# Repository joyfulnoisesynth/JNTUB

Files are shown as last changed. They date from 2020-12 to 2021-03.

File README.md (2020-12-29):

# JoyfulNoise Tiny Utility Board

A versatile ATtiny85-powered Eurorack module in 4HP.

## License

JoyfulNoise hardware and software is Open Source.

The JNTUB hardware is licensed under Creative Commons: [CC-BY-SA-4.0: Attribution / ShareAlike](https://creativecommons.org/licenses/by-sa/4.0/).

The JNTUB firmware is licensed under the GNU General Public License: [GPLv3](https://www.gnu.org/licenses/gpl-3.0-standalone.html).

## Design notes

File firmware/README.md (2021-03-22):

# Joyful Noise Tiny Utility Board Firmware

## Firmware To-Do

### ENV
- [x] Initial implementation
- [x] Refactor to use `FastClock`
- [ ] Make retrig optional
- [ ] Use 10-bit PWM?

### LFO
- [x] Initial implementation
- [x] 10-bit PWM
- [x] Automatic clock detection
- [ ] Fix buggy clock tracking
- [ ] Allow control of amplitude

### VCO
- [x] Initial implementation
- [ ] Adjust SUB/DTN knob response to reflect panel graphics
- [ ] Investigate waveform glitches
- [ ] Ensure audio-rate sync works
- [ ] Experiment with 10-bit audio?
- [ ] Experiment with band-limited wavetables?

### RAND
- [x] Initial implementation
- [ ] Allow control of randomness and/or slew
- [ ] Make it faster?

### Beat Tool
- [x] Implement clock generation
- [x] Implement clock division
- [x] Implement clock multiplication
- [x] Implement burst generation
- [ ] Refactor to use `FastClock`
- [ ] Program the "internal clock" signal chain logic
- [ ] Implement swing
- [ ] Implement gate delay
- [ ] Implement gate lengthen
- [ ] Implement random sequencing
- [ ] Implement euclidean sequencing

### QUANT
- [ ] Initial implementation

### CV Tool
- [ ] Initial implementation

### µTM
- [ ] Initial implementation
- [ ] Implement random gates
- [ ] Implement chaining

### RAT
- [x] Port and test Muskrat firmware
- [ ] Improve user interface

### DSL
- [ ] Port and test Dialup firmware
- [ ] Improve user interface

### STRANG
- [x] Initial Karplus-Strong implementation
- [ ] Much more experimenting to get a decent instrument out of it
- [ ] Experiment with 10-bit audio?

### LFG
- [ ] Initial implementation

### CHRD
- [ ] Initial implementation

### GRNS
- [ ] Port and test Grains firmware
- [ ] Port and test alternative Grains firmwares?
- [ ] Port and test TOOL firmwares?

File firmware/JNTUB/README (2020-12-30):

JoyfulNoise Tiny Utility Board Firmware Library
-----------------------------------------------

This is the library that houses common code that can be used by any
JNTUB-based Eurorack module.

=== USAGE ===

To get this to work with Arduino IDE, you'll need to create a symlink/hardlink
to the firmware/JNTUB/ directory in your Arduino libraries directory.

See <https://www.arduino.cc/en/hacking/libraries> for details.

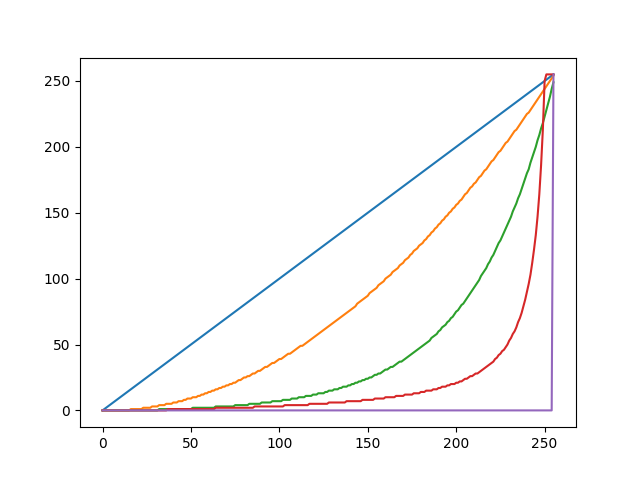
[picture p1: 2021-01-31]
firmware/ENV/curves.png

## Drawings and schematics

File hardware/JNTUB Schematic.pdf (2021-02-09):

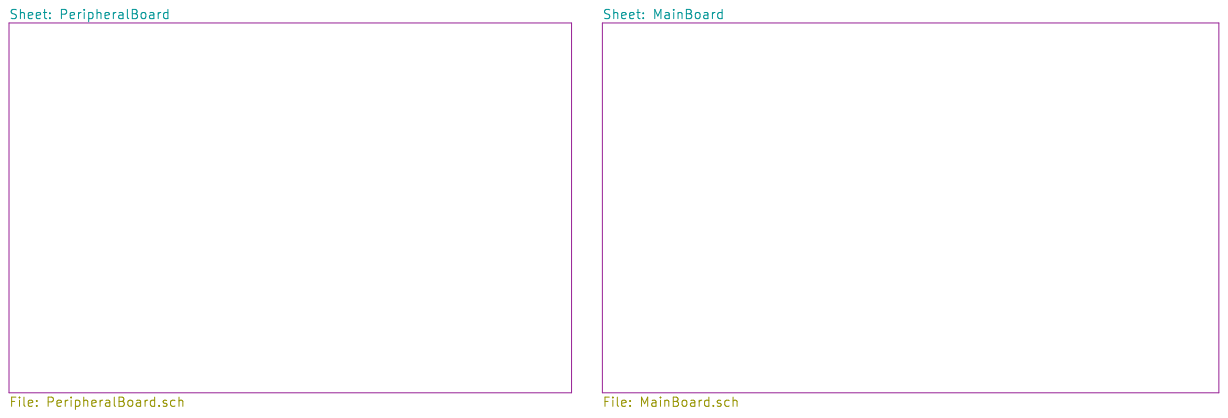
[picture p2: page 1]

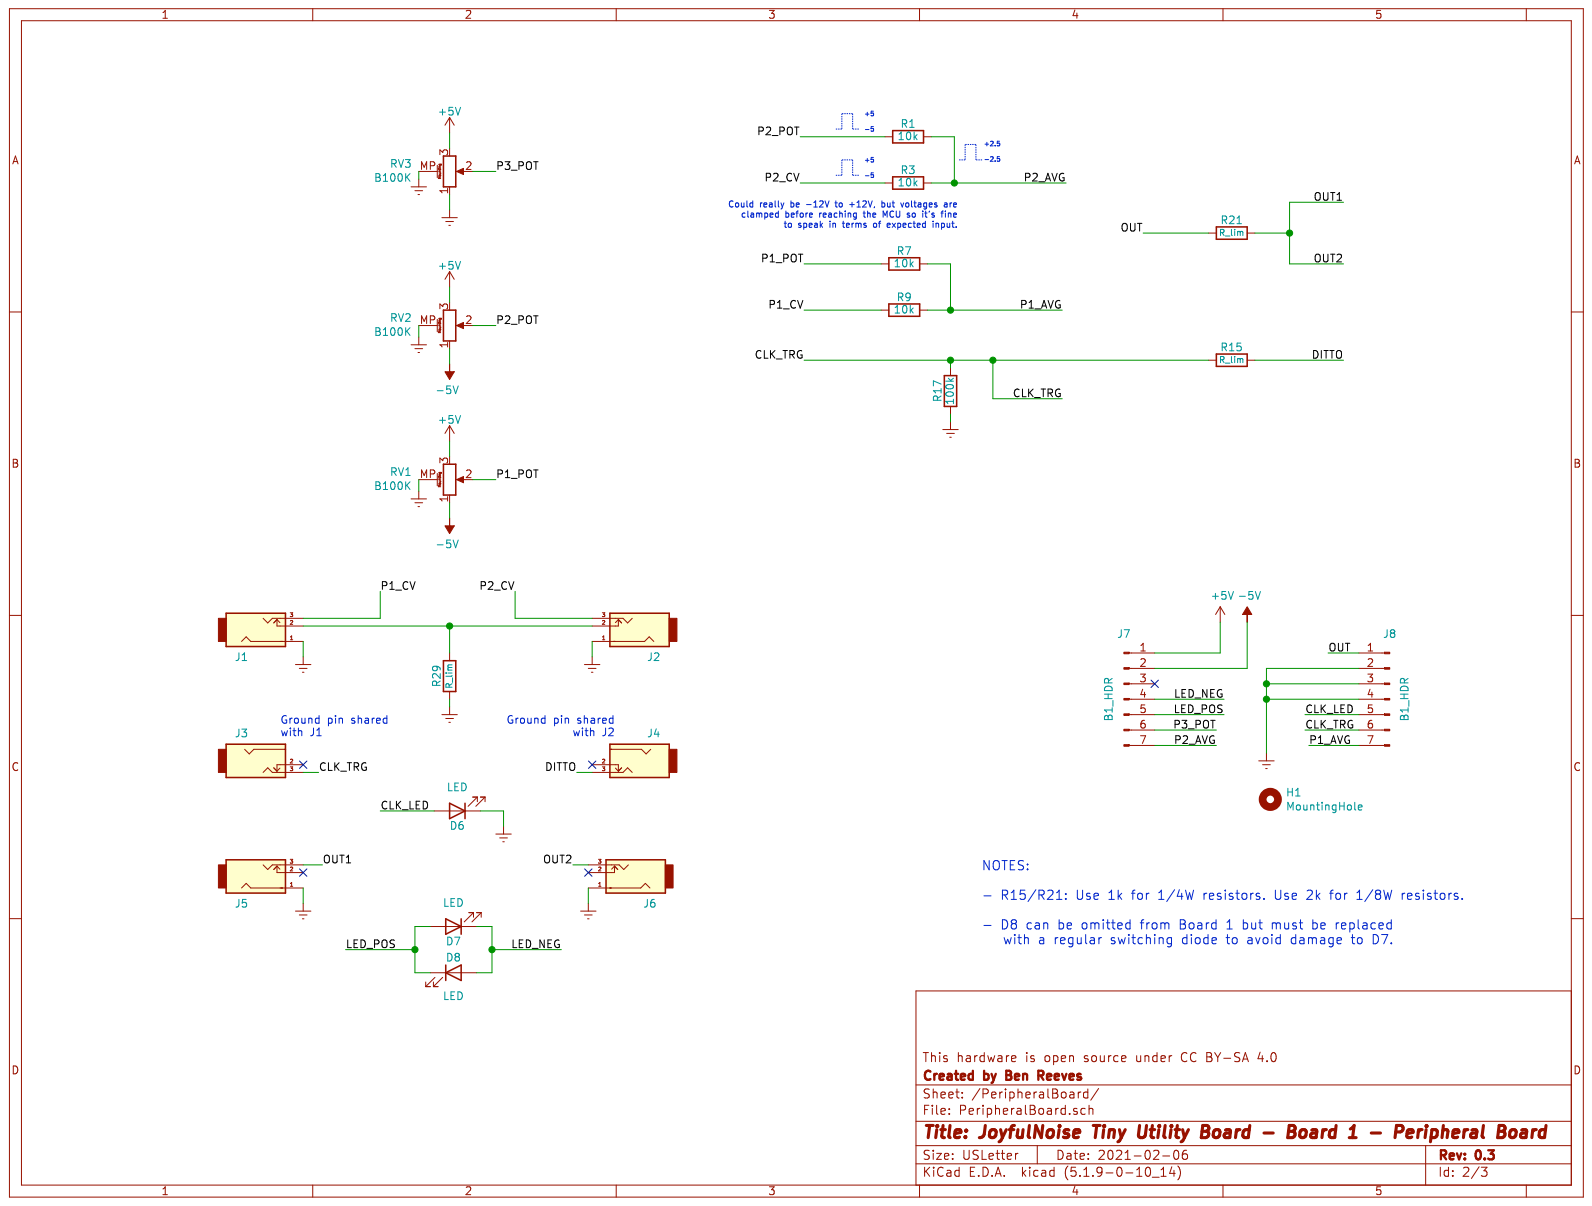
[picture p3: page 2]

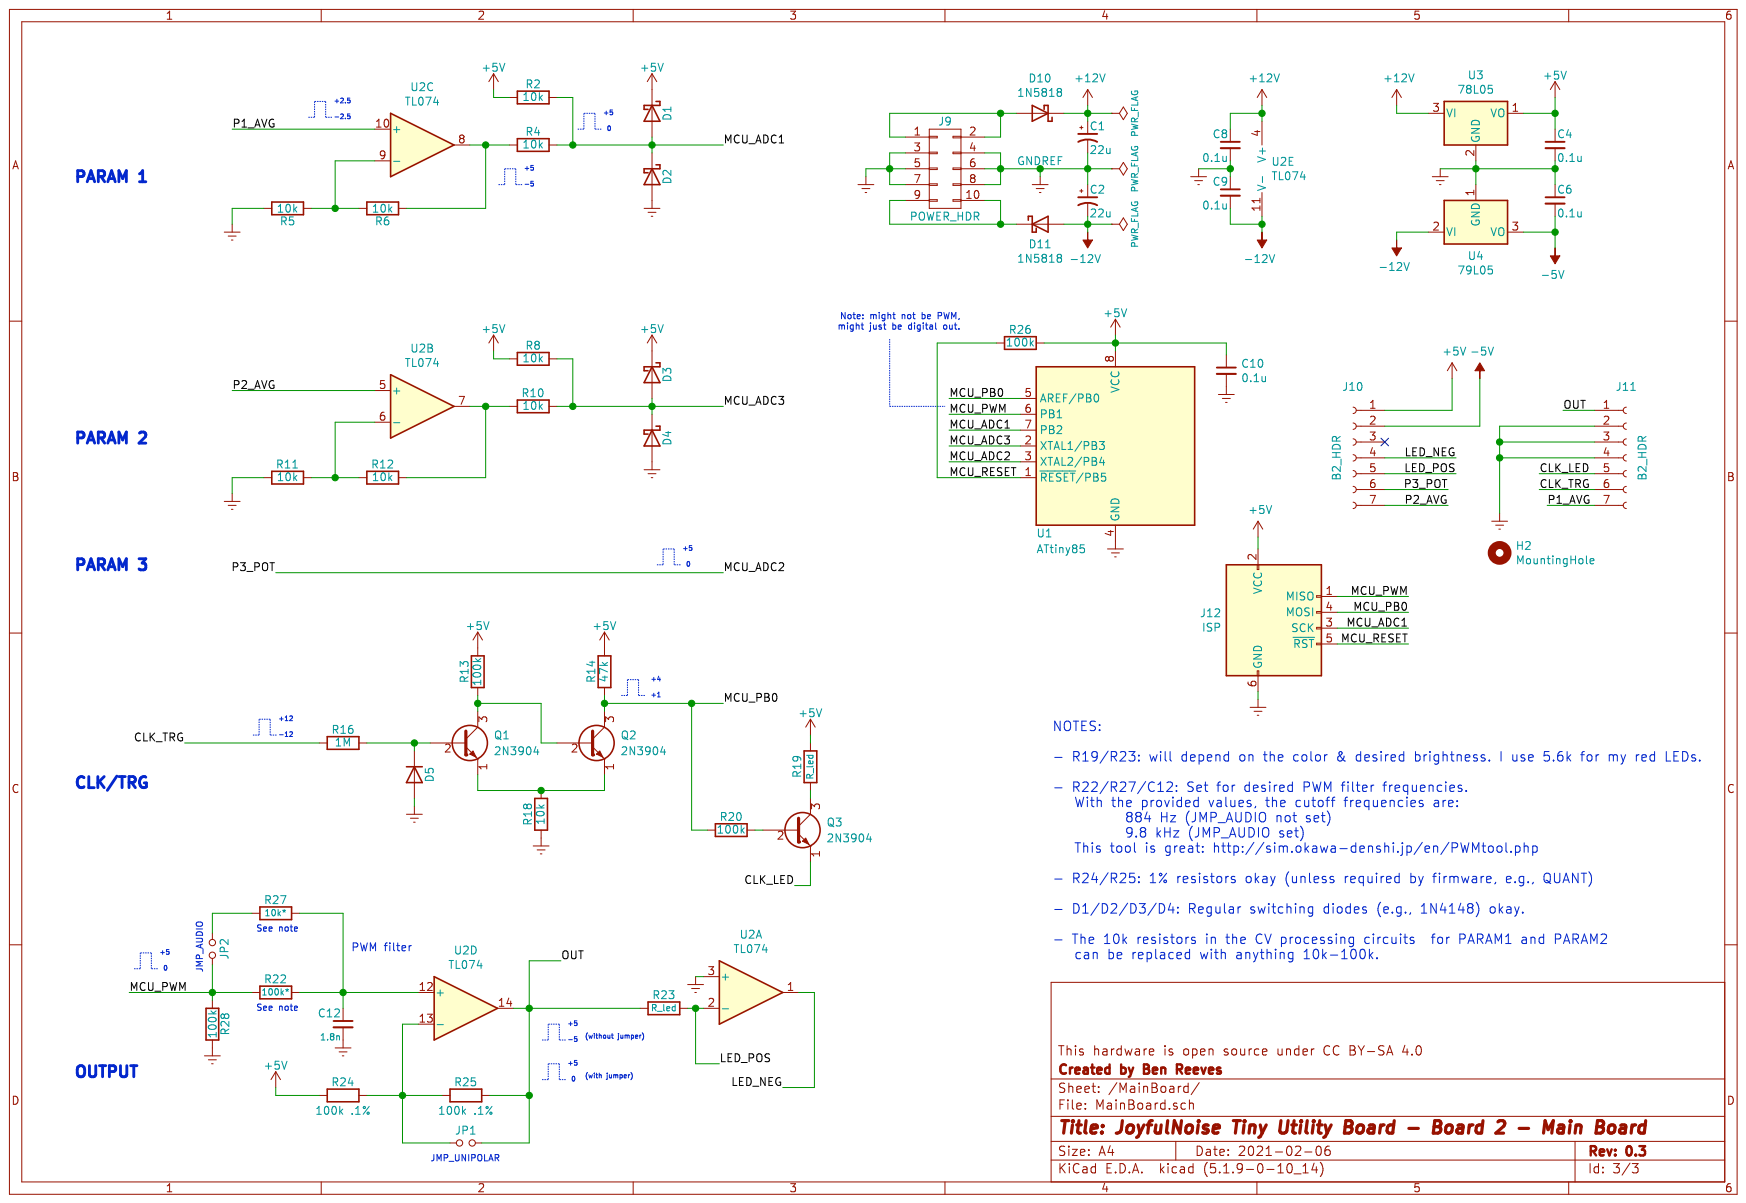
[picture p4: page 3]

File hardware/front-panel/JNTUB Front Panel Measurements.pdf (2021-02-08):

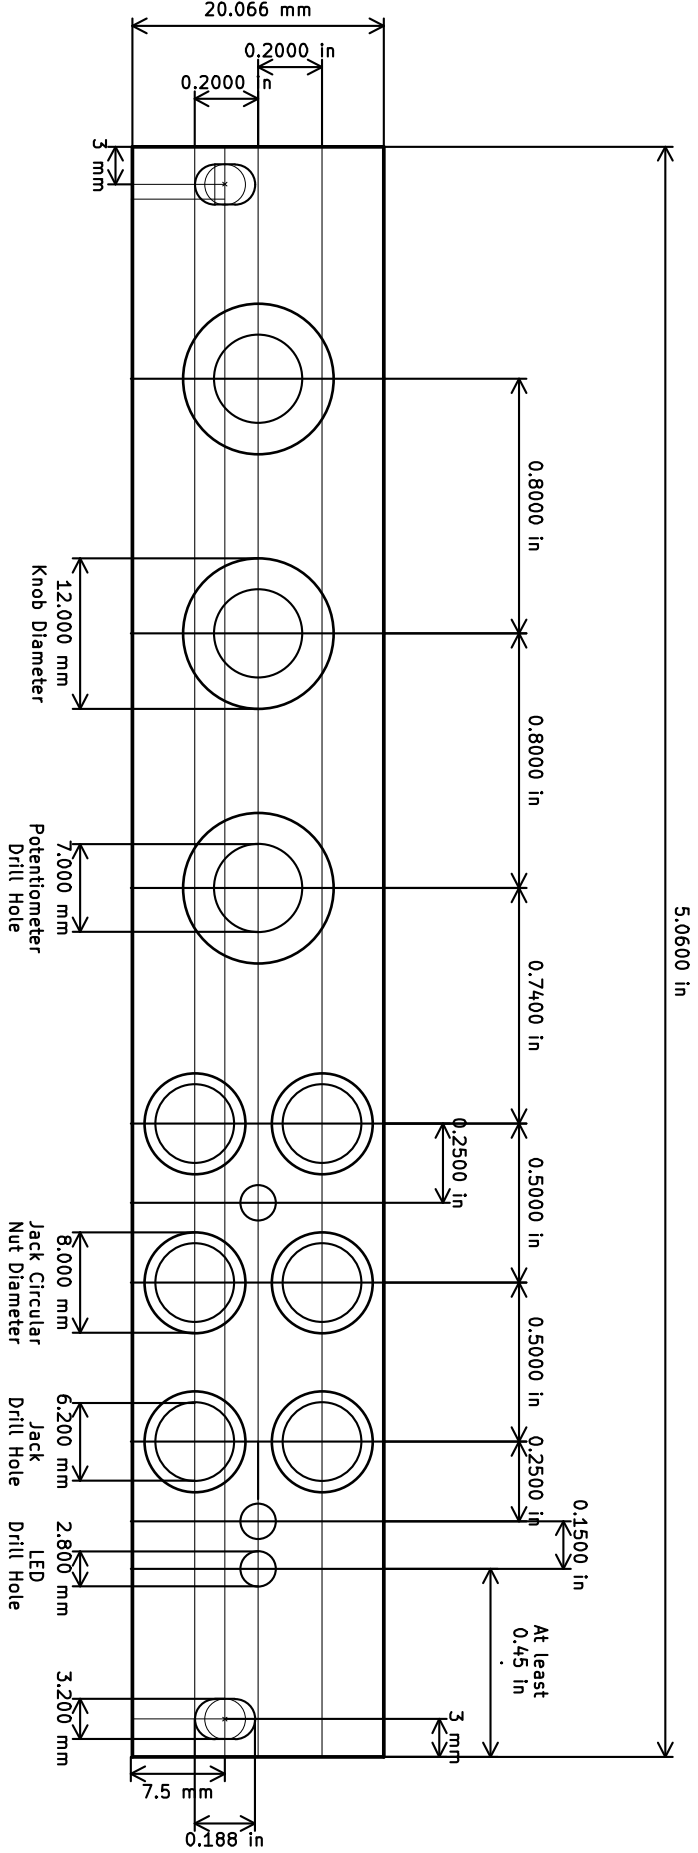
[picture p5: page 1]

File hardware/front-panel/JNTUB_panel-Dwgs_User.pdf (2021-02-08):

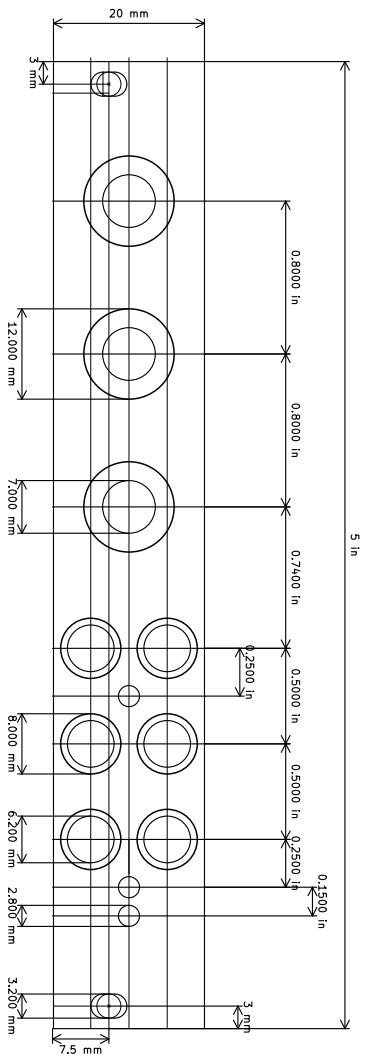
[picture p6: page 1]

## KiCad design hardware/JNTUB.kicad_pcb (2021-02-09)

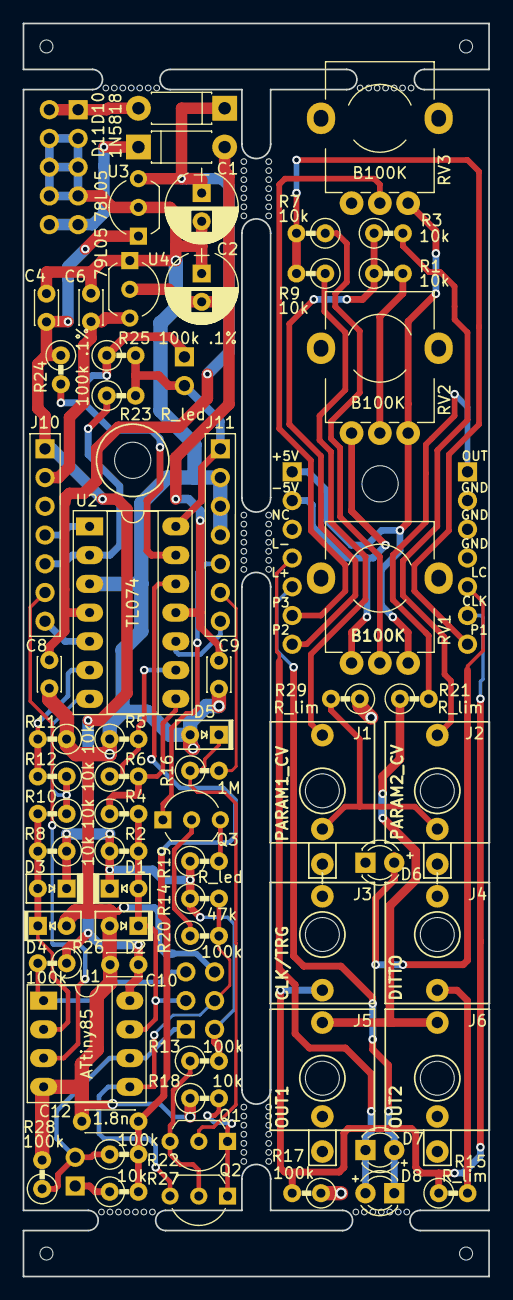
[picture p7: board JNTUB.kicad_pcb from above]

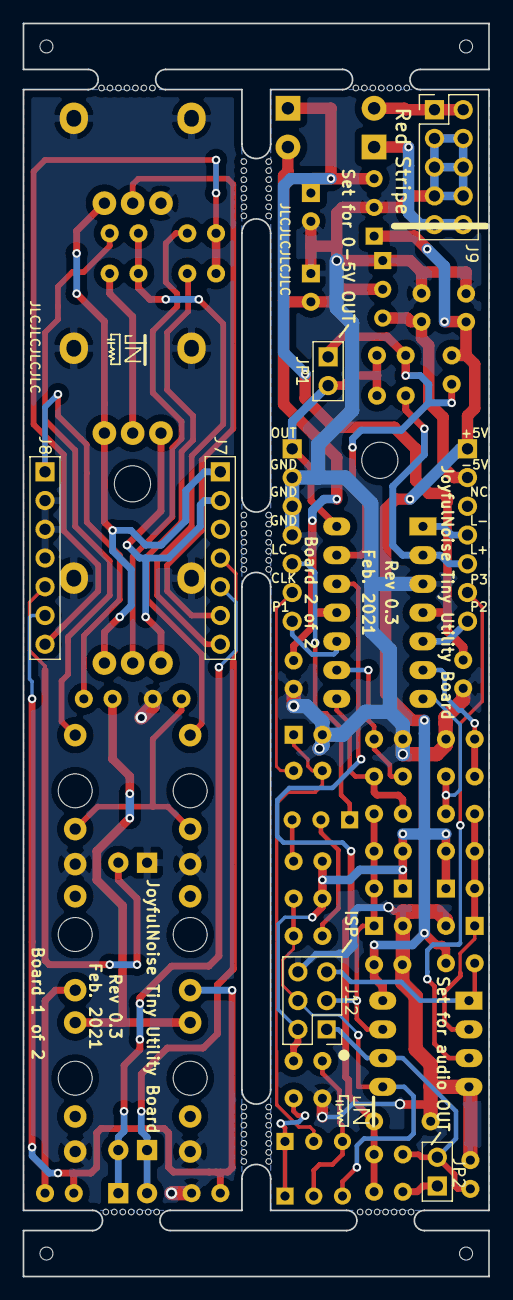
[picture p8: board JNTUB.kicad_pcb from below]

Board: 2 copper layers, 41.1 x 110.7 mm, 80 parts (6 on the bottom side), 47 nets.

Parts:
C1, C2: 22u; CP_Radial_D6.3mm_P2.50mm
C4, C6, C8, C9, C10: 0.1u; C_Disc_D3.0mm_W2.0mm_P2.50mm
C12: 1.8n; C_Disc_D4.3mm_W1.9mm_P5.00mm
D1, D3: BAT81; D_DO-35_SOD27_P2.54mm_Vertical_AnodeUp
D2, D4: BAT81; D_DO-35_SOD27_P2.54mm_Vertical_KathodeUp
D5: 1N4148; D_DO-35_SOD27_P2.54mm_Vertical_KathodeUp
D6, D7, D8: LED; LED_D3.0mm
D10, D11: 1N5818; D_DO-41_SOD81_P7.62mm_Horizontal
H1, H2: MountingHole; MountingHole_3.2mm_M3
J1: PARAM1_CV; PJ301M-12_Thonkiconn
J2: PARAM2_CV; PJ301M-12_Thonkiconn
J3: CLK/TRG; PJ301M-12_Thonkiconn_NoGround
J4: DITTO; PJ301M-12_Thonkiconn_NoGround
J5: OUT1; PJ301M-12_Thonkiconn
J6: OUT2; PJ301M-12_Thonkiconn
J7: B1_HDR_LEFT; Pin_Header_Straight_1x07_Pitch2.54mm
J8: B1_HDR_RIGHT; Pin_Header_Straight_1x07_Pitch2.54mm
J9: POWER; Pin_Header_Straight_2x05_Pitch2.54mm
J10: B2_HDR_LEFT; Pin_Header_Straight_1x07_Pitch2.54mm
J11: B2_HDR_RIGHT; Pin_Header_Straight_1x07_Pitch2.54mm
J12: ISP; Pin_Header_Straight_2x03_Pitch2.54mm
JP1: JMP_UNIPOLAR; Pin_Header_Straight_1x02_Pitch2.54mm
JP2: JMP_AUDIO; Pin_Header_Straight_1x02_Pitch2.54mm
Q1, Q2, Q3: 2N3904; TO-92_Inline_Wide
R1, R2, R3, R4, R5, R6, R7, R8, R9, R10, R11, R12, R18, R27: 10k; R_Axial_DIN0207_L6.3mm_D2.5mm_P2.54mm_Vertical
R13, R17, R20, R22, R26, R28: 100k; R_Axial_DIN0207_L6.3mm_D2.5mm_P2.54mm_Vertical
R14: 47k; R_Axial_DIN0207_L6.3mm_D2.5mm_P2.54mm_Vertical
R15, R21, R29: R_lim; R_Axial_DIN0207_L6.3mm_D2.5mm_P2.54mm_Vertical
R16: 1M; R_Axial_DIN0207_L6.3mm_D2.5mm_P2.54mm_Vertical
R19, R23: R_led; R_Axial_DIN0207_L6.3mm_D2.5mm_P2.54mm_Vertical
R24, R25: 100k .1%; R_Axial_DIN0207_L6.3mm_D2.5mm_P2.54mm_Vertical
RV1, RV2, RV3: B100K; Potentiometer_Alpha_9mm_WithGround
U1: ATtiny85; DIP-8_W7.62mm_Socket_LongPads
U2: TL074; DIP-14_W7.62mm_Socket_LongPads
U3: 78L05; TO-92_Inline_Wide
U4: 79L05; TO-92_Inline_Wide
mouse-bite-2.54mm-slot, mouse-bite-2.54mm-slot#2, mouse-bite-2.54mm-slot#3: VAL**; mouse-bite-2.54mm-slot-long
mouse-bite-2mm-slot, mouse-bite-2mm-slot#2, mouse-bite-2mm-slot#3, mouse-bite-2mm-slot#4: VAL**; mouse-bite-2mm-slot-long-single

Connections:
+5V: C4.1, C10.1, D1.1, D3.1, J7.1, J10.1, J12.2, R2.1, R8.1, R13.2, R14.1, R19.1, R24.1, R26.1, RV1.3, RV2.3, RV3.3, U1.8, U3.1
+12V: C1.1, C8.1, D10.1, U2.4, U3.3
-5V: C6.2, J7.2, J10.2, RV1.1, RV2.1, U4.3
-12V: C2.2, C9.2, D11.2, U2.11, U4.2
/MainBoard/CLK_LED: J11.5, Q3.1
/MainBoard/CLK_TRG: J11.6, R16.2
/MainBoard/LED_NEG: J10.4, U2.1
/MainBoard/LED_POS: J10.5, R23.1, U2.2
/MainBoard/MCU_ADC1: D1.2, D2.1, J12.3, R2.2, R4.2, U1.7
/MainBoard/MCU_ADC2: J10.6, U1.3
/MainBoard/MCU_ADC3: D3.2, D4.1, R8.2, R10.2, U1.2
/MainBoard/MCU_PB0: J12.4, Q2.3, R14.2, R20.2, U1.5
/MainBoard/MCU_PWM: J12.1, JP2.2, R22.1, R28.1, U1.6
/MainBoard/MCU_RESET: J12.5, R26.2, U1.1
/MainBoard/OUT: J11.1, JP1.2, R23.2, R25.2, U2.14
/MainBoard/P1_AVG: J11.7, U2.10
/MainBoard/P2_AVG: J10.7, U2.5
/PeripheralBoard/CLK_LED: D6.2, J8.5
/PeripheralBoard/CLK_TRG: J3.3, J8.6, R15.1, R17.2
/PeripheralBoard/DITTO: J4.3, R15.2
/PeripheralBoard/LED_NEG: D7.1, D8.2, J7.4
/PeripheralBoard/LED_POS: D7.2, D8.1, J7.5
/PeripheralBoard/OUT: J8.1, R21.2
/PeripheralBoard/OUT1: J5.3, J6.3, R21.1
/PeripheralBoard/P1_AVG: J8.7, R7.2, R9.2
/PeripheralBoard/P1_CV: J1.3, R9.1
/PeripheralBoard/P1_POT: R7.1, RV1.2
/PeripheralBoard/P2_AVG: J7.7, R1.1, R3.1
/PeripheralBoard/P2_CV: J2.3, R3.2
/PeripheralBoard/P2_POT: R1.2, RV2.2
/PeripheralBoard/P3_POT: J7.6, RV3.2
GNDREF: C1.2, C2.1, C4.2, C6.1, C8.2, C9.1, C10.2, C12.2, D2.2, D4.2, D5.2, D6.1, J1.1, J2.1, J5.1, J6.1, J8.2, J8.3, J8.4, J9.3, J9.4, J9.5, J9.6, J9.7, J9.8, J11.2, J11.3, J11.4, J12.6, R5.1, R11.1, R17.1, R18.1, R28.2, R29.1, RV1.MP, RV2.MP, RV3.1, RV3.MP, U1.4, U2.3, U3.2, U4.1
unnamed: C12.1, R22.2, R27.2, U2.12
unnamed: D5.1, Q1.2, R16.1
unnamed: D10.2, J9.1, J9.2
unnamed: D11.1, J9.9, J9.10
unnamed: J1.2, J2.2, R29.2
unnamed: JP1.1, R24.2, R25.1, U2.13
unnamed: JP2.1, R27.1
unnamed: Q1.1, Q2.1, R18.2
unnamed: Q1.3, Q2.2, R13.1
unnamed: Q3.2, R20.1
unnamed: Q3.3, R19.2
unnamed: R4.1, R6.2, U2.8
unnamed: R5.2, R6.1, U2.9
unnamed: R10.1, R12.1, U2.7
unnamed: R11.2, R12.2, U2.6

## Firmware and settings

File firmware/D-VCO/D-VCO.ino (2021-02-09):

/*
  Copyright (C) 2021  Ben Reeves

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
  ==============================================================================

  Project:     JoyfulNoise D-VCO
  File:        D-VCO.ino
  Description: Digital, 4-Voice, Morphing Wavetable VCO in 4HP

 */

// JoyfulNoise Tiny Utility Board Library
#include <JNTUB.h>

// Wavetables and note data
#include "Tables.h"

#define isneg(a) (a < 0)
#define neg(a) (~a + 1)

/**
 * Blends between two values with no divides.
 * For blend=0, returns a
 * For blend=64, returns average of a and b
 * For blend=128, returns b
 *
 * XXX: Turns out this is too slow! Curse you, multiplication!!
 * Attempt 1 to fix: make fastBlend where I do a manual less-than-8-bit
 * multiplication by hand with shifts and adds.
 * If that doesn't work, I will store the blended wavetable in memory
 * compute the whole thing during loop().
 */
int8_t blend(int8_t a, int8_t b, uint8_t blend)
{
  if (blend > 128)
    blend = 128;
  // Guaranteed to not overflow. INT8_MAX * 64 + INT8_MAX * 64 == 2^14 - 1
  int16_t aScaled = a * (128-blend);
  int16_t bScaled = b * blend;
  return (aScaled + bScaled) >> 7;
  //return (blend > 64) ? b : a;
}

/**
 * Quickly multiply an unsigned byte by some small value no greater than max.
 */
uint16_t fastMultiplyUnsigned(uint8_t op, uint8_t multiplicand, uint8_t max)
{
  // result = op * 2^0 * (multiplicand & 2^0) +
  //          op * 2^1 * (multiplicand & 2^1) +
  //          etc...
  uint8_t N = 1;
  int16_t opTimesN = op;
  int16_t result = 0;

  while (N <= max) {
    result += (multiplicand & N) ? opTimesN : 0;
    N = N << 1;
    opTimesN = opTimesN << 1;
  }

  return result;
}

/**
 * Quickly multiply a signed byte by some small signed value no greater
 * than +max and no less than -max.
 */
int16_t fastMultiplySigned(int8_t op, int8_t multiplicand, int8_t max)
{
  bool negateResult = 0;
  if (isneg(op)) {
    op = neg(op);
    negateResult ^= 1;
  }
  if (isneg(multiplicand)) {
    multiplicand = neg(multiplicand);
    negateResult ^= 1;
  }
  uint16_t result = fastMultiplyUnsigned(op, multiplicand, max);
  return negateResult ? neg(result) : result;
}

/**
 * Blends between two values with no divides or multiplies.
 * For blend=0, returns a
 * For blend=16, returns average of a and b
 * For blend=32, returns b
 */
int8_t fastBlend(int8_t a, int8_t b, uint8_t blend)
{
  if (blend > 32)
    blend = 32;

  int16_t aScaled = fastMultiplySigned(a, 32 - blend, 32);
  int16_t bScaled = fastMultiplySigned(b, blend, 32);
  return (aScaled + bScaled) >> 5;
}


/**
 * Single-voice wavetable oscillator.
 */
template<typename WavetableT>
class Oscillator {
private:
  // Some indexable wavetable.
  const WavetableT *mWavetable;

  // Phase accumulator.
  uint16_t mPhase;

  // Pitch of the oscillator expressed as fraction of periods per sample.
  uint16_t mPitch;

public:
  Oscillator()
  {
    mPhase = 0;
    mPitch = 0;
    mWavetable = nullptr;
  }

  inline void setPitch(uint16_t pitch)
  {
    mPitch = pitch;
  }

  inline void setPhase(uint16_t phase)
  {
    mPhase = phase;
  }

  inline void setWavetable(const WavetableT *wavetable)
  {
    mWavetable = wavetable;
  }

  inline int8_t getSample()
  {
    mPhase += mPitch;
    if (mWavetable)
      return mWavetable->getValue(mPhase);
    return 0;
  }
};

/**
 * Indexable wavetable of size 2^N stored in SRAM.
 */
template<unsigned N>
class SRAMWavetable {
private:
  int8_t mTable[1<<N];

public:
  SRAMWavetable() {
    // Fill table with zeros.
    memset(mTable, 0, sizeof(mTable));
  }

  int8_t *getPtr()
  {
    return mTable;
  }

  inline int8_t getValue(uint16_t phase) const
  {
    uint16_t index = phase >> (16-N);
    return mTable[index];
  }
};

/**
 * The wavetables to be blended between.
 */
#define NUM_WAVETABLES 4
const int8_t *const WAVETABLES[NUM_WAVETABLES] = {
  WT_SINE,
  WT_TRIANGLE,
  WT_SAWTOOTH,
  WT_SQUARE,
};

/**
 * The multiplications required to compute the blended wave shape
 * are too expensive to perform during each sample.
 * So instead, we will compute the entire blended wavetable during
 * loop() and store it in memory, and then switch over the pointer
 * when we've finished filling the in-memory wavetable.
 *
 * So we'll need to two in-memory tables to switch between.
 * One is on-deck being filled by loop() as quickly as possible,
 * and the other is being read by the oscillator(s).
 *
 * Since there's only 512 bytes of SRAM, we unfortunately can't store
 * two copies of the full wavetables. So chop em in half. 128 samples
 * is still enough to get good waves.
 */
SRAMWavetable<7> BLENDED_WAVETABLES[2];
uint8_t onDeckWavetable;

/**
 * Blends two wavetables together and stores the result in the 128-byte
 * array result.
 */
void blendWavetables(
  const int8_t *tableA,
  const int8_t *tableB,
  uint8_t blendAmt,
  int8_t *result)
{
  for (uint8_t i = 0; i < 128; ++i) {
    int8_t sampA = pgm_read_byte_near(tableA + i*2);
    int8_t sampB = pgm_read_byte_near(tableB + i*2);
    result[i] = blend(sampA, sampB, blendAmt);
  }
}


/**
 * Oscillator voice(s).
 */
#define NUM_OSCS 3
Oscillator<SRAMWavetable<7>> oscs[NUM_OSCS];

// Map input range to midi notes 0 to 119 (10 octaves)
JNTUB::DiscreteKnob pitchKnob(120, 1);

JNTUB::DiscreteKnob waveKnob(NUM_WAVETABLES-1, 1);
uint8_t currentTable;
uint8_t currentBlend;

#define DETUNE_MIN 0
#define DETUNE_MAX 10
#define MAX_SUB_OCTAVE 2
JNTUB::DiscreteKnob detuneKnob(MAX_SUB_OCTAVE + 1, 1);

JNTUB::EdgeDetector sync;

void setup()
{
  onDeckWavetable = 1;
  currentTable = 0;
  currentBlend = 0;

  JNTUB::setUpFastPWM();
  JNTUB::setUpTimerInterrupt(JNTUB::SAMPLE_RATE_20_KHZ);
}

void loop()
{
  uint16_t pitchRaw = analogRead(JNTUB::PIN_PARAM1);
  uint16_t waveRaw = analogRead(JNTUB::PIN_PARAM2);
  uint16_t detuneRaw = analogRead(JNTUB::PIN_PARAM3);
  bool syncRaw = digitalRead(JNTUB::PIN_GATE_TRG);

  pitchKnob.update(pitchRaw);
  waveKnob.update(waveRaw);
  detuneKnob.update(detuneRaw);
  sync.update(syncRaw);

  uint8_t midiNote = pitchKnob.getValue();
  uint16_t pitch = pgm_read_word(&MIDI_NOTE_PITCHES[midiNote]);
  uint8_t subOct = detuneKnob.getValue();
  uint16_t detune = detuneKnob.mapInnerValue(DETUNE_MIN, DETUNE_MAX);
  oscs[0].setPitch(pitch >> subOct);
  oscs[1].setPitch(pitch - detune);
  oscs[2].setPitch(pitch + (detune>>1));
  //oscs[3].setPitch(pitch+detune);

  if (sync.isRising()) {
    for (uint8_t i = 0; i < NUM_OSCS; ++i) {
      oscs[i].setPhase(0);
    }
  }

  uint8_t tableSelect = waveKnob.getValue();
  uint8_t blend = waveKnob.mapInnerValue(0, 128);

  if (tableSelect != currentTable || blend != currentBlend) {
    // Compute new blended wavetable
    blendWavetables(
      WAVETABLES[tableSelect],
      WAVETABLES[tableSelect+1],
      blend,
      BLENDED_WAVETABLES[onDeckWavetable].getPtr());

    currentTable = tableSelect;
    currentBlend = blend;

    // Switch wavetables
    noInterrupts();
    for (uint8_t i = 0; i < NUM_OSCS; ++i) {
      oscs[i].setWavetable(&BLENDED_WAVETABLES[onDeckWavetable]);
    }
    onDeckWavetable = !onDeckWavetable;
    interrupts();
  }

}

ISR(TIMER_INTERRUPT)
{
  int16_t sample1 = oscs[0].getSample() << 1;
  int8_t sample2 = oscs[1].getSample();
  int8_t sample3 = oscs[2].getSample();
  //int8_t sample4 = oscs[3].getSample();
  int16_t sum = (int16_t)sample1 + sample2 + sample3;
  int8_t sample = sum >> 2;
  JNTUB::analogWriteOut(sample + 128);
}

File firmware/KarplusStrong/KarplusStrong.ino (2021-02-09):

/*
  Copyright (C) 2021  Ben Reeves

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
  ==============================================================================

  Project:     Karplus Strong Synthesis on ATTiny85
  File:        KarplusStrong.ino

  BACKGROUND
  ------------------------------------------------------------------------------

  Karplus-Strong synthesis models the sound of a plucked string instrument.
  The basic method of synthesis is fairly simple:

    1) Excite a delay line with some noise,
    2) Set the delay time equal to the desired period of oscillation,
    3) Feed the ouput of the delay line through a lowpass filter
       and then back into itself.

  This causes the contents of the delay line to serve as a morphing wavetable.
  Initially, the wavetable is full of noise, so it is high in harmonic content.
  With every period, the wavetable is filtered and put back into itself, so
  the harmonic content slowly decays, leaving only a periodic oscillation
  at the fundamental frequency.

  This mimics a plucked string. At the onset, the string pluck is high in
  harmonic content, but the harmonic content quickly decays and leaves behind
  the fundamental.

  BASIC ALGORITHM
  ------------------------------------------------------------------------------

  At its most basic, the Karplus-Strong algorithm generates samples as follows:

    Y(t) = X(t)      for t < p

    Y(t) = F(t)      for t >= p

  Where:
    Y(t): output signal at time t
    X(t): exciter signal at time t
    F(t): filtered feedback signal at time t
    p:    period of oscillation in samples

  In other words, for the first p samples, we fill the delay line with some
  exciter signal, and then we continually feed the delayed signal through
  a filter of some sort and back into itself.

  A simple but effective feedback function is:

    F(t) = (Y(t-p) + Y(t-p+1)) / 2

  This is just a two-point average of the (t-p)-th sample and (t-p+1)-th sample.
  This serves a rudimentary lowpass filter on the feedback.

  Something to note: because of this average, the period of oscillation is
  actually (p - 1/2) samples, not p samples. We can fix that later.

  The exciter signal X(t) can be anything, but is usually white noise. We
  can generate X(t) as follows:

           / +A   probability 1/2
   X(t) = |
           \ -A   probability 1/2

  Where A is the amplitude of the exciter. Note that this is not true white
  noise, but that's actually good. The original KP paper notes that this will
  result in a signal that is ~5 dB louder than it would be if we were just
  choosing random numbers between -A and +A.

  MODIFICATION 1: DECAY STRETCHING
  ------------------------------------------------------------------------------

  Because the periods are shorter at higher frequencies, higher notes decay
  much quicker than lower notes. We can modify the algorithm to perform
  decay stretching:

            / F(t)     probability 1/S
    Y(t) = |
            \ Y(t-p)   probability 1 - 1/S

  Where S is denoted the "stretch factor" and is always at least 1.
  In other words, with probability 1/S, perform filtering of the feedback as
  normal. The rest of the time, feed the signal straight back into itself with
  no filtering. Since the filtering is what actually causes the note to decay,
  this has the effect of increasing the decay time by a factor of about S.

  Something to note: when used with the aforementioned two-point average F(t),
  the stretch factor (very slightly) affects the pitch of the note. In fact, a
  higher S makes the pitch more accurate: the period becomes (p - 1/(2S)) rather
  than (p - 1/2).

  MODIFICATION 2: 1-2-1 WEIGHTED AVERAGE
  ------------------------------------------------------------------------------

  An alternative feedback function to the classic two-point average is a 1-2-1
  weighted average over three samples:

    F(t) = (Y(t-p-1) + 2*Y(t-p) + Y(t-p+1)) / 4

  This modification reduces the decay time for all notes compared to the
  two-point average. However, it has the benefit of making the period of
  oscillation exactly p samples rather than (p - 1/2) samples.

  Something to note: due to the new Y(t-p-1) term, the longest period of
  oscillation we can achieve for a given size of delay line (N) is N-1, not N.

  MODIFICATION 3: DRUM SYNTHESIS
  ------------------------------------------------------------------------------

  The original KP paper presents the algorithms as a method of sythesizing
  not only plucked-string sounds, but also drum sounds! The modified
  recurrence relation is as follows:

          /  +F(t)    probability b
  Y(t) = |
          \  -F(t)    probability 1 - b

  Where b is denoted the "blend factor." With b=1, we get the classic plucked-
  string recurrence relation. With b=1/2, the sound is drumlike. With b=0, the
  entire signal is negated every period, dropping the frequency an octave and
  leaving only the odd harmonics of the new fundamental. For values in between,
  the timbre of the sound blends.

  IMPLEMENTATION DETAIL 1: ROUND-OFF ERROR COMPENSATION (DITHERING)
  ------------------------------------------------------------------------------

  Using small word sizes (in our case, 8 bits) makes round-off error a
  noticeable issue. Since each period performs an integer division, we get a
  consistent rounding down over time, which causes notes to decay unnaturally
  quickly.

  The original KP paper suggests a method of eliminating this issue, which is
  to basically randomly add 0 or 1 to the sum of Y(t-p) and Y(t-p+1) before
  dividing by 2. This is referred to as the "dithering" technique.

  If using 1-2-1 scaling rather than the two-point average, we can add a random
  number between 0 and 3 before dividing by 4.
 */

// JoyfulNoise Tiny Utility Board Library
#include <JNTUB.h>

/**
 * Gets random bits and bytes quickly.
 *
 * It turns out that the C library random() function is WAY too expensive
 * to call once every sample. Since I don't feel like taking the time
 * to read an entire computer science textbook chapter on random number
 * generation, I used python to generate some 8-bit white noise and am
 * storing that in program memory :-)
 */
class FastRandom {
private:
  // Chose a prime number for the size of the array to avoid any incidental periodicity.
  static const uint8_t NOISE[1021] PROGMEM;
  uint16_t mIndex;

public:
  FastRandom() : mIndex(0) {}

  inline uint8_t randomByte()
  {
    uint8_t ret = pgm_read_byte(&NOISE[mIndex++]);
    if (mIndex >= 1021)
      mIndex = 0;
    return ret;
  }
};

/**
 * Indexable, FIFO ring buffer.
 */
template<typename T, unsigned N>
class RingBuffer {
private:
  T buf[N];
  uint16_t front;
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

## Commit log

2020-12-30 [JNTUB-fw] Add test pin mappings for ATmega328p
2020-12-30 [JNTUB-fw] Add Test sketch to test JNTUB library
    Also, I was wrong about gate being inverted, fix that.
    [JNTUB.cpp, JNTUB.h, Test.ino]
2021-01-01 [JNTUB-HW] Overhaul PCB layout
    - Make traces and clearances much bigger than first attempt
    - Remove test points and resistor leading to MCU RESET
    - Move some resistors to peripheral board
    - Space out remaining components on main board
    [JNTUB.kicad_pcb, MainBoard.sch, PeripheralBoard.sch]
2021-01-01 [JNTUB-HW] Clean up PCB v0.1 for fabrication
    [JNTUB.kicad_pcb]
2021-01-01 [JNTUB-HW] Write script to copy PCB for splitting
    Need to have separate Gerber files for each board.
    [JNTUB.kicad_pcb]
2021-01-01 [JNTUB-HW] Swap front and back copper layers
    [JNTUB.kicad_pcb]
2021-01-01 [JNTUB-HW] Clean up straggling traces
    [JNTUB.kicad_pcb]
2021-01-01 [JNTUB-HW] Add JLCPCB note for part number
    [JNTUB.kicad_pcb]
2021-01-01 [JNTUB-HW] Generate Gerber files for PCB v0.1
    [JNTUB_board1-B_Cu.gbr, JNTUB_board1-B_Mask.gbr, JNTUB_board1-B_SilkS.gbr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]
2021-01-01 [JNTUB-HW] Update schematic PDF for v0.1
    [JNTUB.sch, MainBoard.sch, PeripheralBoard.sch]
2021-01-01 [JNTUB-fw] Update JNTUB lib interface
    Also lay groundwork for fast PWM
2021-01-01 [JNTUB-fw] Add keywords.txt to JNTUB Arduino lib
2021-01-03 [JNTUB-fw] Fix up Clock and CurveKnob
    [JNTUB.cpp, JNTUB.h]
2021-01-03 [JNTUB-fw] Add Stopwatch to handle timer overflow
2021-01-04 [JNTUB-fw] Fix compile errors
    [JNTUB.cpp, JNTUB.h]
2021-01-04 [JNTUB-fw] Implement fast PWM setup
2021-01-04 [BeatTool] Fix bugs in multiply mode
    [BeatTool.ino]
2021-01-06 [JNTUB-HW] Move front panel to separate PCB file
    [JNTUB.kicad_pcb, JNTUB_panel.kicad_pcb]
2021-01-08 [JNTUB-HW] Finish v0.1 of front panel
    [JNTUB_panel-B_Cu.gbr, JNTUB_panel-B_Mask.gbr, JNTUB_panel-B_SilkS.gbr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]
2021-01-08 [BeatTool] Improve Clock and Burst modes
    * Give better rate ranges for both Clock and Burst modes.
    * Run both modes off milliseconds rather than microseconds.
2021-01-18 [JNTUB-HW] JNTUB Hardware Revision 0.2
    * Add resistor to drain C12 (PWM filter cap)
    * Add optional parallel resistor to PWM filter
    * selectable by jumper
    * increases the cutoff frequency to audio range
    * Add resistor between 5V and MCU RESET to allow for ISP
    * Move a few resistors to Board 1
    * Add ISP programming headers!
    * Change all resistors and diodes to standing
    * Shorten pin headers that connect Boards 1 and 2
    * Ditch ground pour on Board 1 in favor of direct traces
    * Move CV 1 and CV 2 jacks down a bit
    * Slightly adjust LED positions
    * Adjust front panel to match moved components
    * Tweak design of front panel
    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
    [JNTUB.kicad_pcb, JNTUB.sch, JNTUB_panel.kicad_pcb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]
2021-01-18 [JNTUB-HW] Generate Gerber files for v0.2
    [JNTUB_board1-B_Cu.gbr, JNTUB_board1-B_Mask.gbr, JNTUB_board1-B_SilkS.gbr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]
2021-01-20 [JNTUB-HW] Re-export panel as old gerber (for JLC)
    [JNTUB_panel-B_Cu.gbr, JNTUB_panel-B_Mask.gbr, JNTUB_panel-B_SilkS.gbr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]
2021-01-31 [Karplus] Fix things and experiment a bit
    * Fix weighted average arithmetic bug
    * Fix blend parameter
    * Try new weights for weighted average
    [KarplusStrong.ino]
2021-01-31 [JNTUB-fw] Version-specific pin mappings
    The pin mappings changed between hardware v0.1 and v0.2.
    Since I have test units with both hardware versions, I
    added the ability to #define HW_VER_0_1 before importing
    JNTUB.h to change them.
2021-02-05 [JNTUB-HW] Shift panel holes down a bit
    [JNTUB_panel.kicad_pcb]
2021-02-05 [JNTUB-HW] Modify resistor values in schematic
    [JNTUB.kicad_pcb, MainBoard.sch, PeripheralBoard.sch]
2021-02-05 [JNTUB-HW] Some PCB and schematic updates
    * Thicker silkscreen on diodes
    * Give explicit values to some items
    * Update potentiometer schematic symbols
    * Fix some symbol names
    [JNTUB.kicad_pcb, MainBoard.sch, PeripheralBoard.sch]
2021-02-06 [JNTUB-HW] Create SMD version of PCB
    Use KiCad scripting API to write a script to turn most
    through-hole parts into SMT parts. Will use this to release
    two variants of the board.
    Had to reroute many traces so that every through hole pad is
    connected to traces on the front layer (that way, when all
    the through holes are removed, the components are still
    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
    [JNTUB.kicad_pcb, MainBoard.sch]
2021-02-07 [JNTUB-HW] PCB now preparable for SMT assembly!
    [JNTUB.kicad_pcb, MainBoard.sch, PeripheralBoard.sch]
2021-02-07 [JNTUB-HW] Import Simon's panel designs into KiCad
    [JNTUB_panel.kicad_pcb, JNTUB_panels.kicad_pcb]
2021-02-08 [JNTUB-fw] Implement a 10-bit PWM procedure
2021-02-08 [JNTUB-HW] Prepare a smaller mfg batch of panels
    [JNTUB_panels.kicad_pcb, JNTUB_panels_all.kicad_pcb]
2021-02-09 [JNTUB-HW] JNTUB Hardware Revision 0.3
    [JNTUB.kicad_pcb, JNTUB.sch, MainBoard.sch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]
2021-02-09 [JNTUB-HW] Generate Gerber files for v0.3
    [JNTUB_board1-B_Cu.gbr, JNTUB_board1-B_Mask.gbr, JNTUB_board1-B_SilkS.gbr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]
2021-02-09 [JNTUB-fw] Rename AudioInterrupt -> TimerInterrupt
    Gonna also use this facility for FastClock in the next commit
2021-02-12 [JNTUB-fw] Better timer interrupt support
2021-02-12 [JNTUB-fw] Make 10-bit PWM actually work
2021-02-12 [LFO] Use 10-bit PWM for less chunky output
2021-02-12 [LFO] Fix bug where amplitude was 1/4 of expected
    [LFO.ino]
2021-02-14 [JNTUB-fw] Construct FastClock with a sample rate
2021-03-18 [JNTUB-fw] Pin mappings for HW v0.3

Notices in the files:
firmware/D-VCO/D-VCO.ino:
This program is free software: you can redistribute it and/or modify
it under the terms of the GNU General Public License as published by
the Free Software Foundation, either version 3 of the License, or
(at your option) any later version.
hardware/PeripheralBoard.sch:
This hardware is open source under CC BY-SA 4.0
